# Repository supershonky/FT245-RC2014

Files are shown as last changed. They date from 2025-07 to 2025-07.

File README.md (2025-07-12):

# FT245-RC2014
An add-on board for the RC2014 bus using the FT245 as an ACIA/UART replacement

Files are Kicad 9 format.

The FT245 is a USB-FIFO IC. That is, it appears to be a COM port at the PC, but it has a bidirectional tristate data bus, read and write enables, and a couple of status lines. With minimal logic it can be interfaced to an 8 bit micro to provide power and a serial connection that requires no configuration at either end. Fed up of trying to work out what serial port settings to use? This doesn't care. Use any baud rate you like, the chip will still transfer at 12Mbps. Sick of trying to get weird UARTs to work in assembly language? Fear not, simply check the status "register" at BASE+0x00, and then write to, or read from BASE+0x01. It doesn't get easier!

This version is compatible with the RC2014 standard (and enhanced) bus, and appears as a MC6850. Sort of. SCM and BASIC do not use interrupts, so seem to work fine. CP/M needs an interrupt on receive, but the FT245 doesn't provide an interrupt, so the logic fakes one. It's enough to get CP/M up and running, but because there is no flow control logic, transmit delays may still be needed for some applications. With a 1ms character delay, using download to transfer packages was still faster than the SIO provided as part of the RC2014 Pro kit.

This is provided as-is, use at your own risk, I do not accept any responsibility for damages however caused.

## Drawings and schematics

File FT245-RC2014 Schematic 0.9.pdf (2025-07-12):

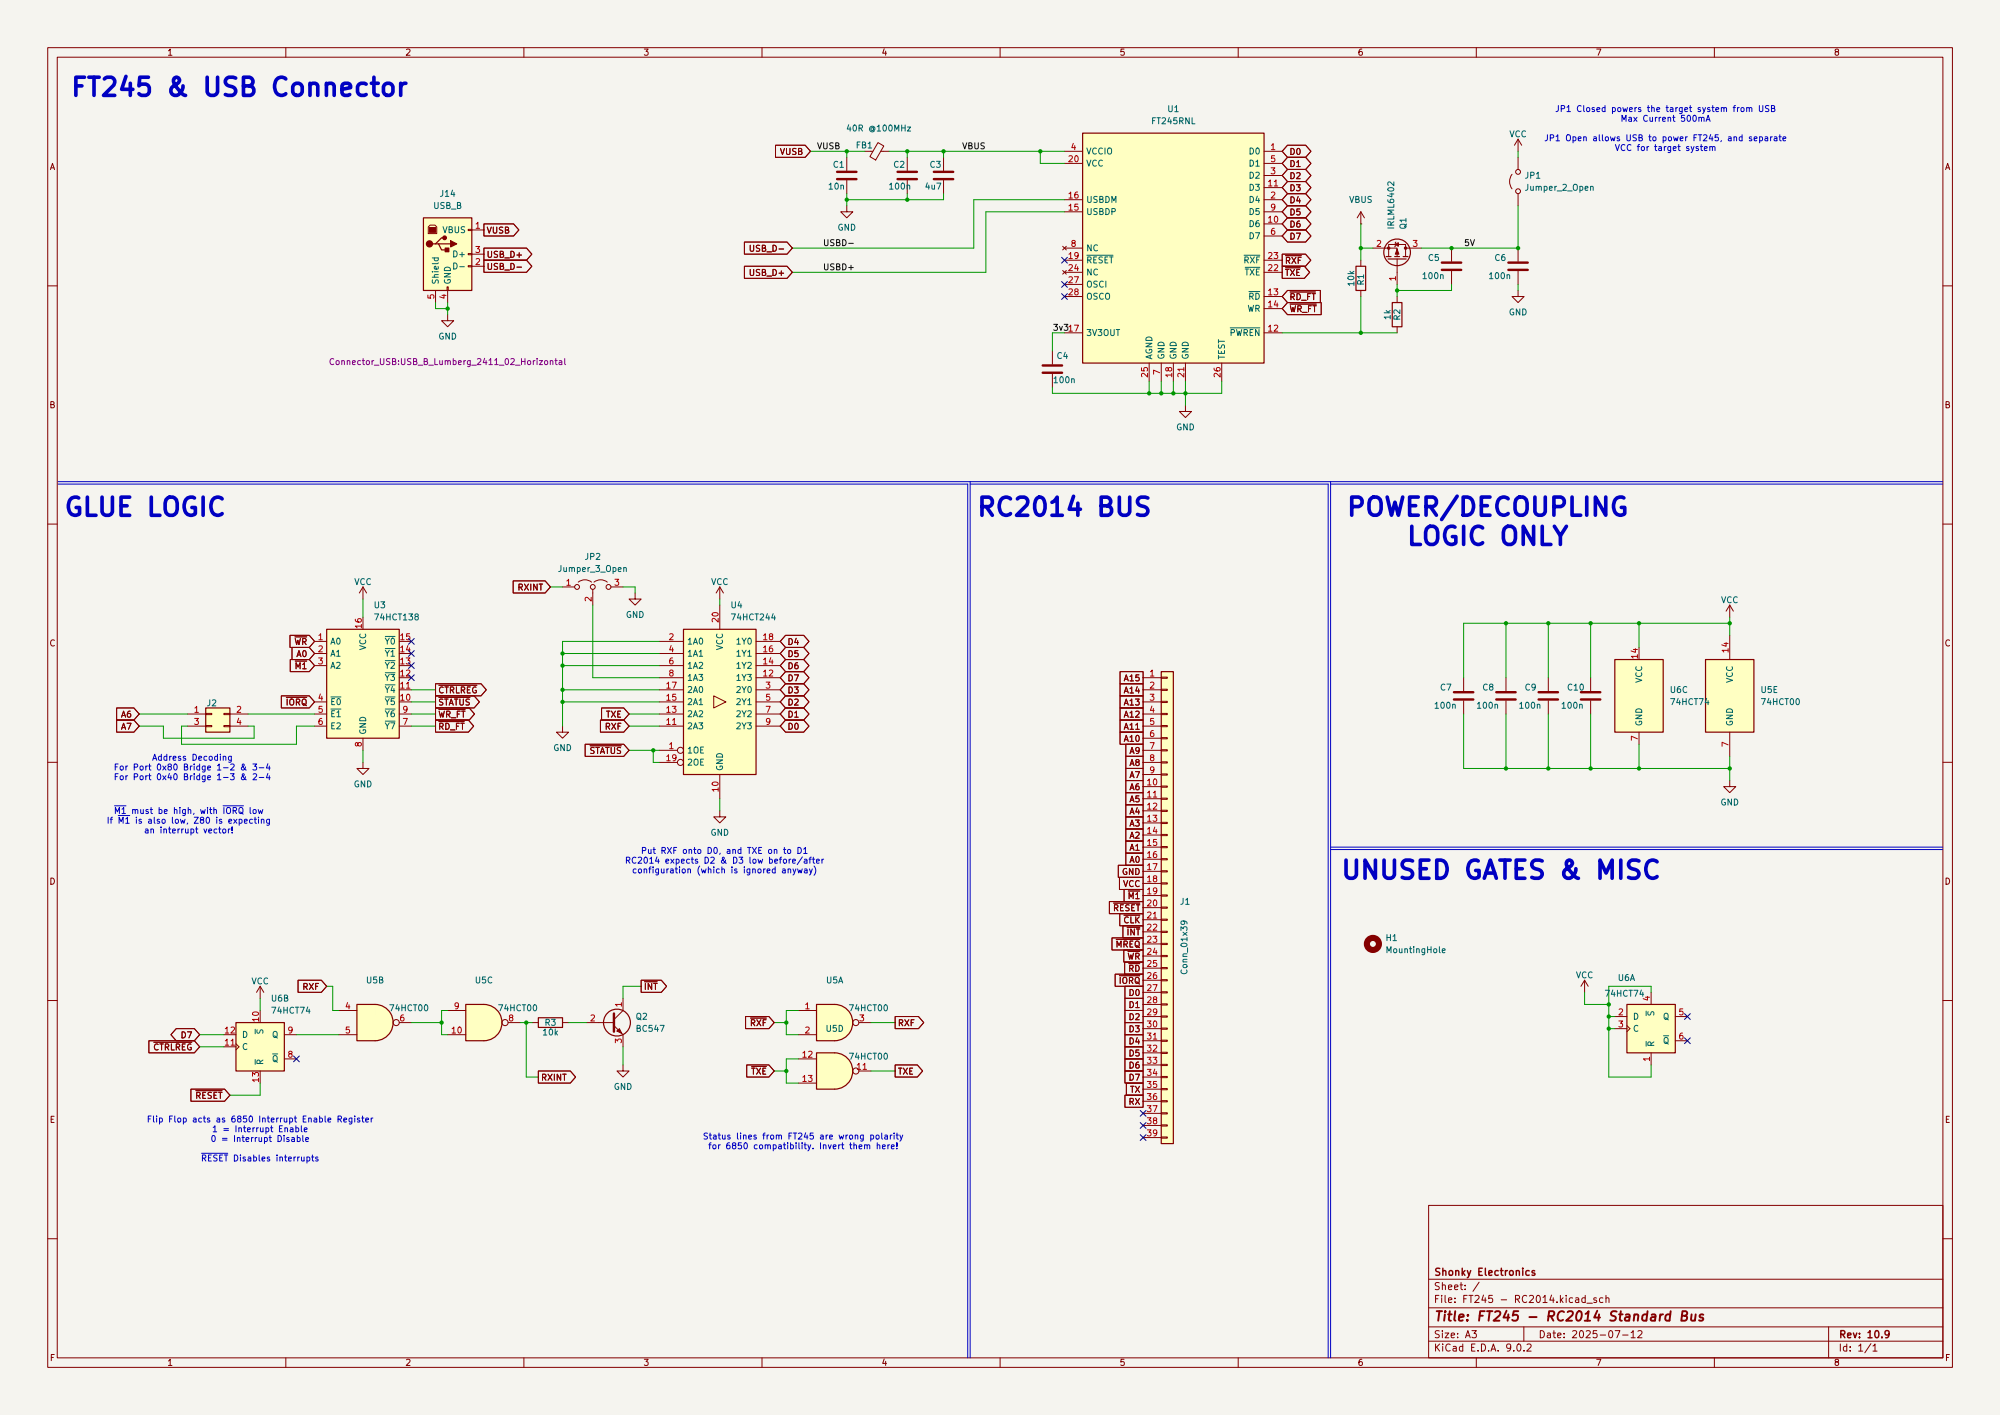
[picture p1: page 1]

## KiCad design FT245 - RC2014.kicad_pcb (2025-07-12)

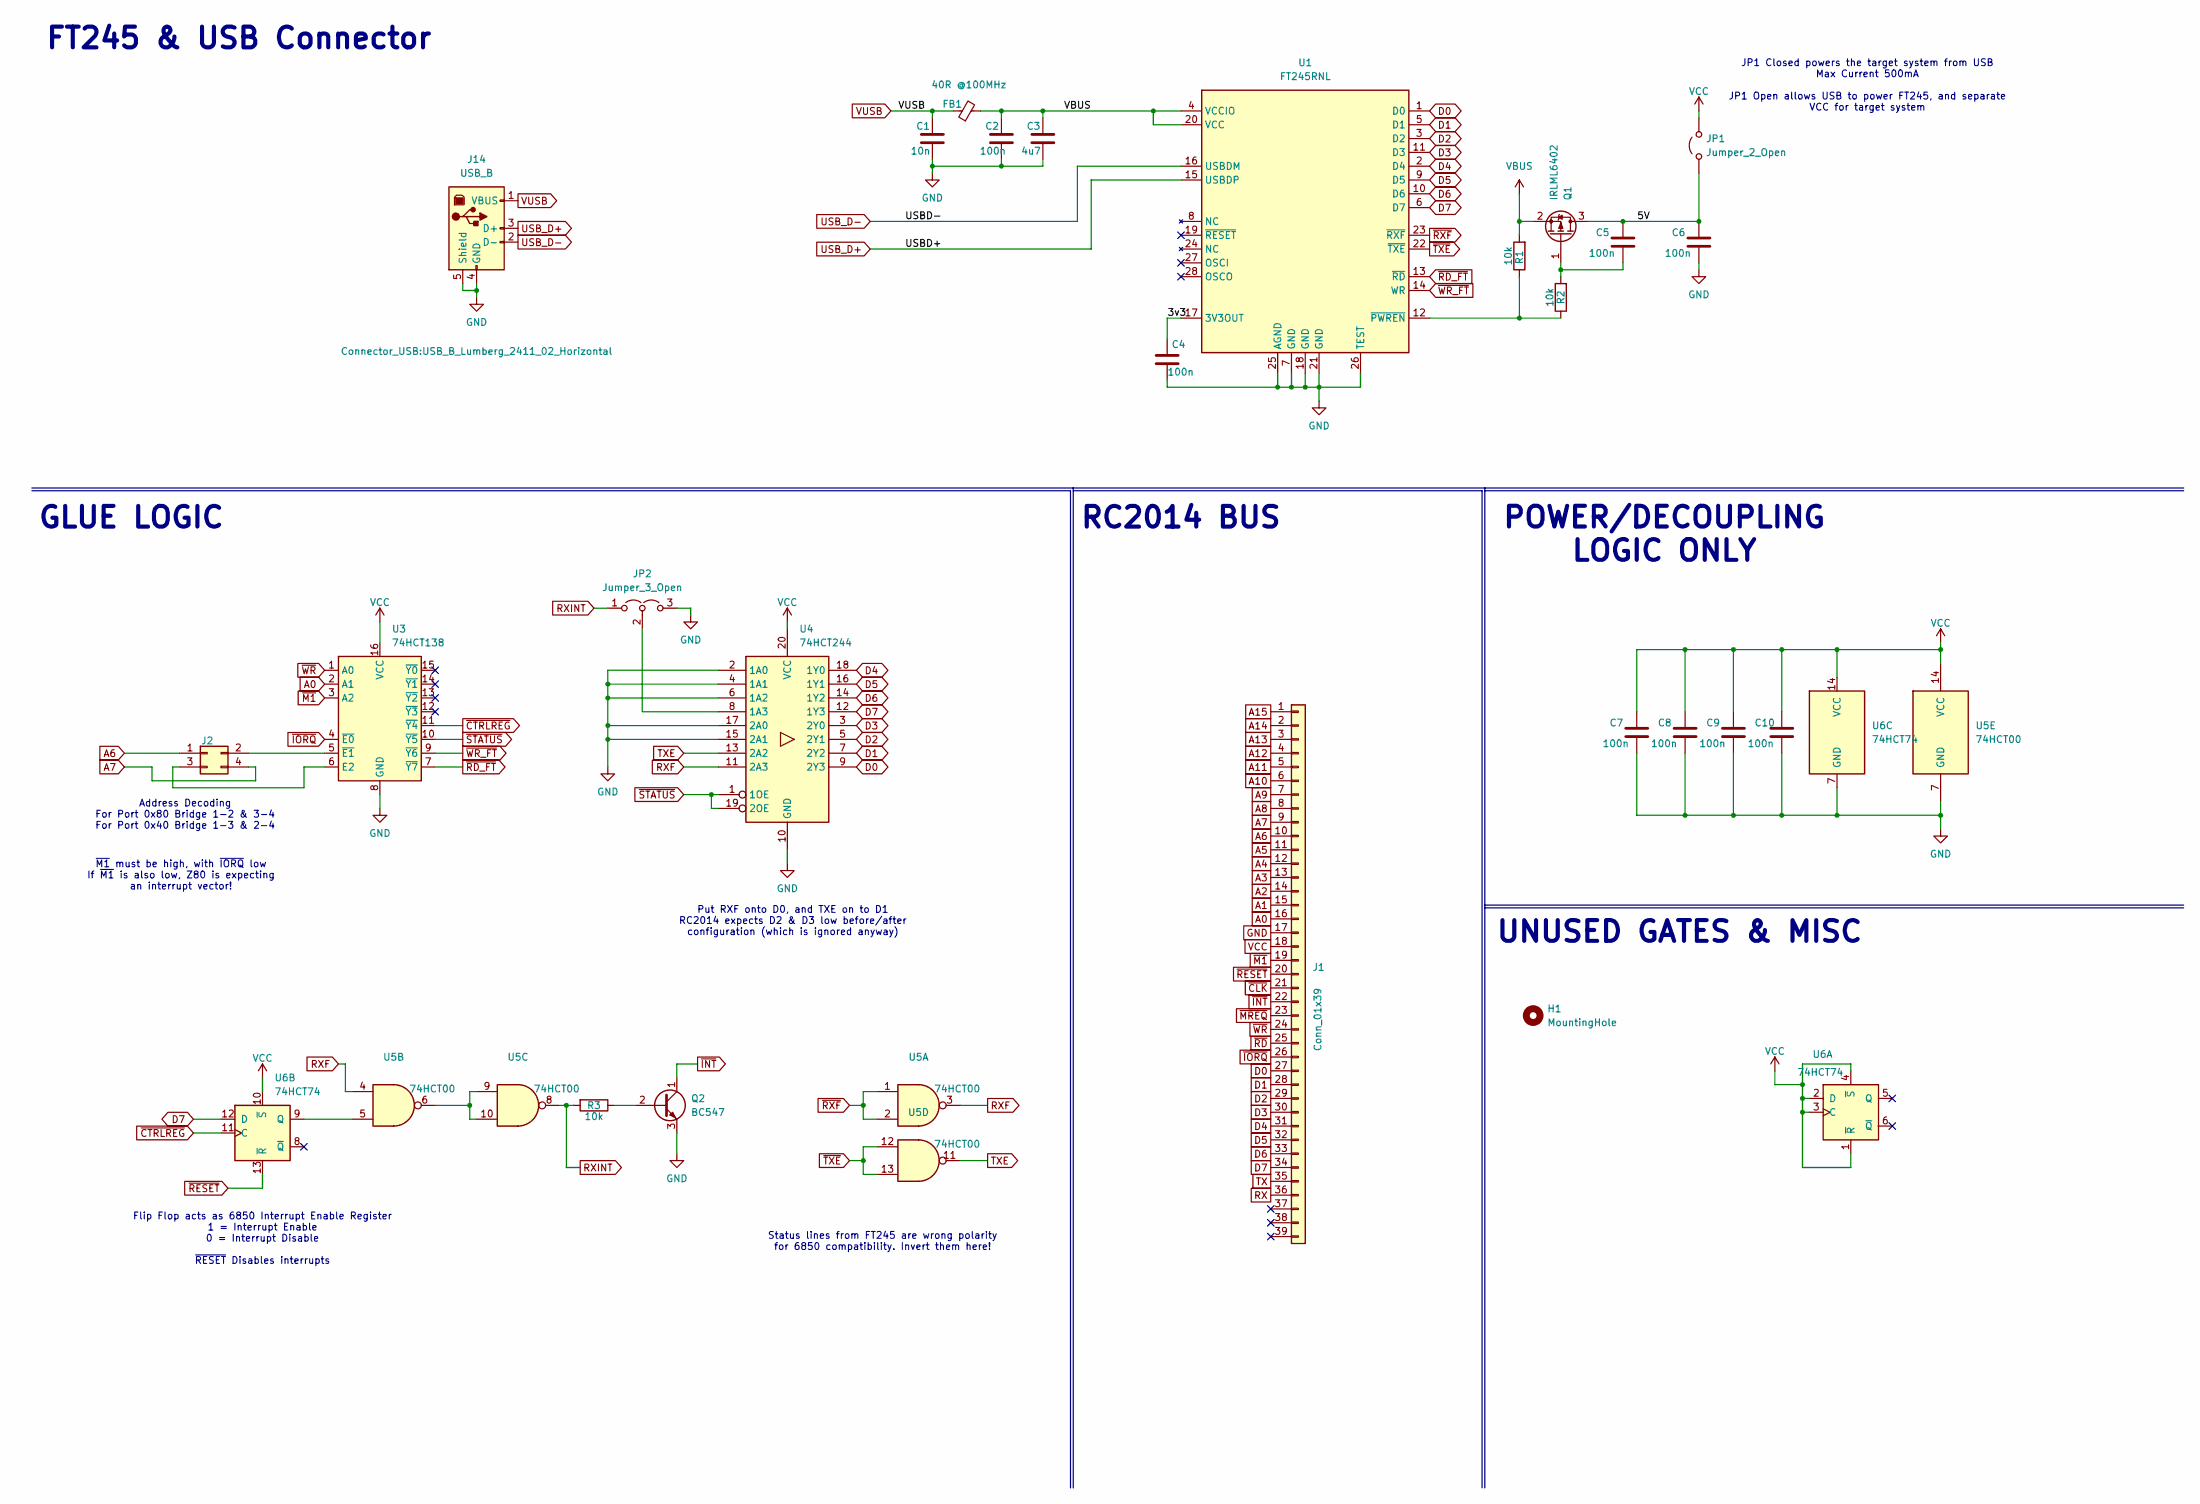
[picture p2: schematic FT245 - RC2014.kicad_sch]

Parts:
C1: 10n; C_0603_1608Metric_Pad1.08x0.95mm_HandSolder; LCSC C1524
C2, C4, C5, C6: 100n; C_0603_1608Metric_Pad1.08x0.95mm_HandSolder; LCSC C1525
C3: 4u7; C_0603_1608Metric_Pad1.08x0.95mm_HandSolder; LCSC C1525
C7, C8, C9, C10: 100n; C_Rect_L4.0mm_W2.5mm_P2.50mm; LCSC C1525
FB1: 40R @100MHz; C_0805_2012Metric; LCSC C369522
H1: MountingHole; MountingHole_3.2mm_M3
J1: Conn_01x39; PinHeader_1x39_P2.54mm_Vertical
J2: Conn_02x02_Odd_Even; PinHeader_2x02_P2.54mm_Vertical
J14: USB_B; USB_B_Lumberg_2411_02_Horizontal
JP1: Jumper_2_Open; PinHeader_1x02_P2.54mm_Vertical
JP2: Jumper_3_Open; SolderJumper-3_P1.3mm_Open_RoundedPad1.0x1.5mm
Q1: IRLML6402; SOT-23; LCSC C5182043
Q2: BC547; TO-92_Wide
R1, R2: 10k; R_0603_1608Metric_Pad0.98x0.95mm_HandSolder; LCSC C25744
R3: 10k; R_Axial_DIN0204_L3.6mm_D1.6mm_P7.62mm_Horizontal; LCSC C25744
U1: FT245RNL; SSOP-28_5.3x10.2mm_P0.65mm; LCSC DNF
U3: 74HCT138; DIP-16_W7.62mm
U4: 74HCT244; DIP-20_W7.62mm
U5: 74HCT00; DIP-14_W7.62mm
U6: 74HCT74; DIP-14_W7.62mm

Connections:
/3v3: C4.1, U1.17 (3V3OUT)
/5V: C5.1, C6.1, JP1.1 (A), Q1.3 (D)
A0: J1.16, U3.2 (A1)
A1: J1.15
A2: J1.14
A3: J1.13
A4: J1.12
A5: J1.11
A6: J1.10, J2.1
A7: J1.9, J2.4
A8: J1.8
A9: J1.7
A10: J1.6
A11: J1.5
A12: J1.4
A13: J1.3
A14: J1.2
A15: J1.1
D0: J1.27, U1.1 (D0), U4.9 (2Y3)
D1: J1.28, U1.5 (D1), U4.7 (2Y2)
D2: J1.29, U1.3 (D2), U4.5 (2Y1)
D3: J1.30, U1.11 (D3), U4.3 (2Y0)
D4: J1.31, U1.2 (D4), U4.18 (1Y0)
D5: J1.32, U1.9 (D5), U4.16 (1Y1)
D6: J1.33, U1.10 (D6), U4.14 (1Y2)
D7: J1.34, U1.6 (D7), U4.12 (1Y3), U6.12 (D)
GND: C1.2, C2.2, C3.2, C4.2, C6.2, C7.2, C8.2, C9.2, C10.2, J1.17, J14.4 (GND), J14.5 (Shield), JP2.3 (B), Q2.3 (E), U1.7 (GND), U1.18 (GND), U1.21 (GND), U1.25 (AGND), U1.26 (TEST), U3.8 (GND), U4.2 (1A0), U4.4 (1A1), U4.6 (1A2), U4.10 (GND), U4.15 (2A1), U4.17 (2A0), U5.7 (GND), U6.7 (GND)
unnamed: J2.2, U3.5 (~E1)
unnamed: J2.3, U3.6 (E2)
unnamed: JP2.2 (C), U4.8 (1A3)
unnamed: C5.2, Q1.1 (G), R2.2
unnamed: Q2.2 (B), R3.1
unnamed: R1.1, R2.1, U1.12 (~PWREN)
unnamed: U5.6, U5.9, U5.10
unnamed: U5.5, U6.9 (Q)
RX: J1.36
RXF: U4.11 (2A3), U5.3, U5.4
RXINT: JP2.1 (A), R3.2, U5.8
TX: J1.35
TXE: U4.13 (2A2), U5.11
USB_D+: J14.3 (D+), U1.15 (USBDP)
USB_D-: J14.2 (D-), U1.16 (USBDM)
VBUS: C2.1, C3.1, FB1.2, Q1.2 (S), R1.2, U1.4 (VCCIO), U1.20 (VCC)
VCC: C7.1, C8.1, C9.1, C10.1, J1.18, JP1.2 (B), U3.16 (VCC), U4.20 (VCC), U5.14 (VCC), U6.1 (~R), U6.2 (D), U6.3 (C), U6.4 (~S), U6.10 (~S), U6.14 (VCC)
VUSB: C1.1, FB1.1, J14.1 (VBUS)
~CLK: J1.21
~CTRLREG: U3.11 (~Y4), U6.11 (C)
~INT: J1.22, Q2.1 (C)
~IORQ: J1.26, U3.4 (~E0)
~M1: J1.19, U3.3 (A2)
~MREQ: J1.23
~RD_FT: U1.13 (~RD), U3.7 (~Y7)
~RD: J1.25
~RESET: J1.20, U6.13 (~R)
~RXF: U1.23 (~RXF), U5.1, U5.2
~STATUS: U3.10 (~Y5), U4.1 (1OE), U4.19 (2OE)
~TXE: U1.22 (~TXE), U5.12, U5.13
~WR_FT: U1.14 (WR), U3.9 (~Y6)
~WR: J1.24, U3.1 (A0)

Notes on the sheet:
~{M1} must be high, with ~{IORQ} low If ~{M1} is also low, Z80 is expecting an interrupt vector!
RC2014 BUS
GLUE LOGIC
Address Decoding For Port 0x80 Bridge 1-2 & 3-4 For Port 0x40 Bridge 1-3 & 2-4
FT245 & USB Connector
Status lines from FT245 are wrong polarity for 6850 compatibility. Invert them here!
JP1 Closed powers the target system from USB Max Current 500mA JP1 Open allows USB to power FT245, and separate VCC for target system
POWER/DECOUPLING LOGIC ONLY
Flip Flop acts as 6850 Interrupt Enable Register 1 = Interrupt Enable 0 = Interrupt Disable ~{RESET} Disables interrupts
Put RXF onto D0, and TXE on to D1 RC2014 expects D2 & D3 low before/after configuration (which is ignored anyway)
UNUSED GATES & MISC

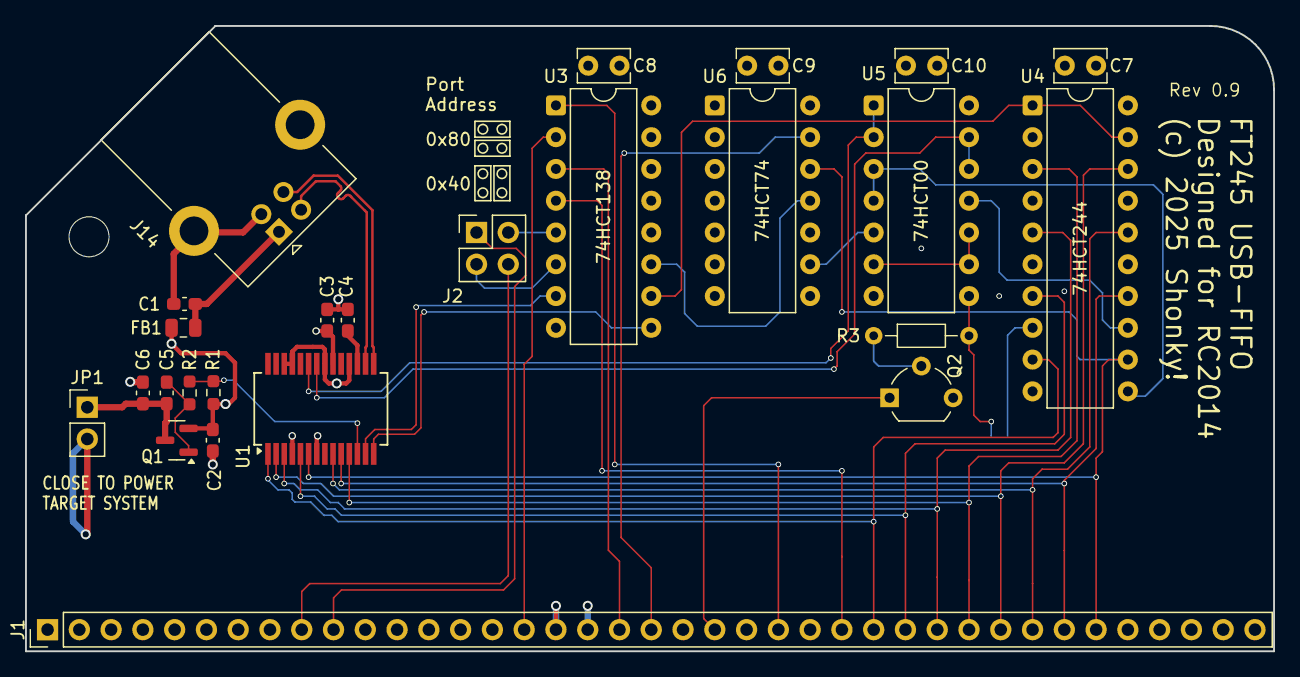
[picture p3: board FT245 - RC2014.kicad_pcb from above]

Board: 4 copper layers, 99.8 x 50.0 mm, 27 parts (1 on the bottom side), 41 nets.

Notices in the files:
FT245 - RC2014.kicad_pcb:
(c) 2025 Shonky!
